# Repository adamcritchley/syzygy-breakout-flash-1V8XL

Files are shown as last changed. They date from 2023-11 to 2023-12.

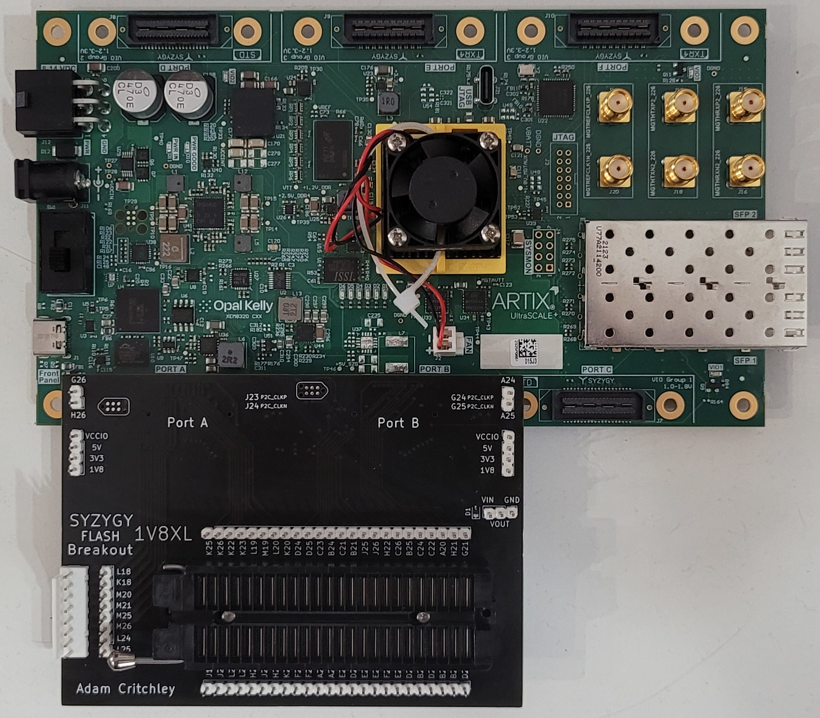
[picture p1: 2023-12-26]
images/top_on_board.jpg

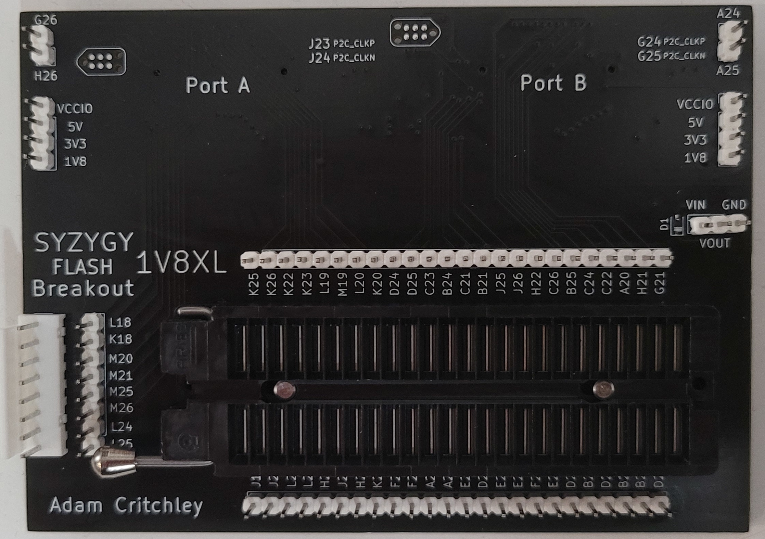
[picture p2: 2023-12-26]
images/top.jpg

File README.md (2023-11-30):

# Double-Wide SYZYGY Breakout Flash
SYZYGY 56 pin Breakout Board that uses smart VIO to support any voltage flash chip. I wanted a way to experiment with flash without having to spin a new board for each footprint or solder yet another BGA or TSOP. Flash programmers with ZIF adapters seemed like the best choice and SYZYGY would make it compatible with a wide range of FPGA boards. This is the biggest and baddest version of the other SYZYGY flash breakout boards and requires the smart VIO in the SYZYGY DNA to be set to your flash logic level. It requires two adjacent standard ports which can only be found on a handful of FPGA dev boards such as the [Opal Kelly XEM8320](https://opalkelly.com/products/xem8320/).

# Building Firmware
A prebuilt firmware has been provided in the 'firmware' directory. If you want to customize the SMART VIO then modify 'szg-flash-std.json' with the custom power values and use the official [SYZYGY tools](https://github.com/SYZYGYfpga/syzygy-tools/) repo to build the firmware. 

```bash
python ..\..\syzygy-tools\dna-tools\syzygy-tools.py -d ..\szg-dna\SZG-FLASH\szg-flash-std.json -f ..\..\syzygy-tools\pod-fw\avr-dna-fw-main.hex
```

# Fabrication
I used JLCPCB with 1oz inner and outer copper weight and the standard JLC041611-7628 impedance control.

# FPGA Development
The board has silkscreen pin designators for the Opal Kelly XEM8320. Theoretically you can use this board with any FPGA dev board that has a double-wide SYZYGY connector along with the respective controller for your flash device OR find someway to expose it to AXI and PS to use it with flashrom. As I figure out specific tools that work well then I'll update this README with tutorials.

# BOM
You can find datasheets for each component in the datasheets directory. All of the components can be bought from Mouser or Digikey. 
* Epson SG5032VAN (up to 100 MHz)
* Texas Instrument TLV1117LV
* Aries 48-6554-11
* KF2510 8-pin Vertical Connector

# Future Work
This board design is complete and tested with the Opal Kelly XEM8320. As I find/create IP and software that works with this board then I'll update this README with tutorials on how to use them. Feel free to create a GitHub issue detailing your own success story or use case.

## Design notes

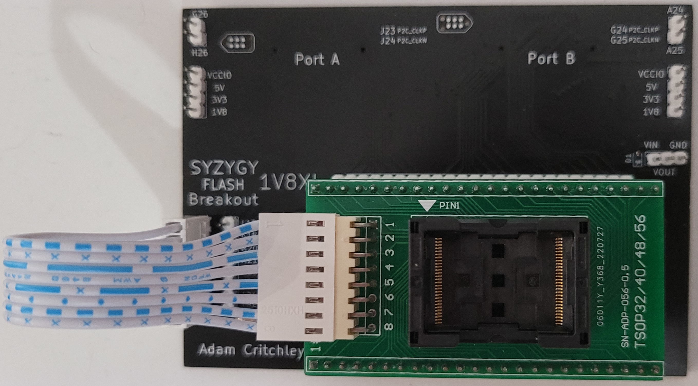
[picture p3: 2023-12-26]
images/top_with_socket.jpg

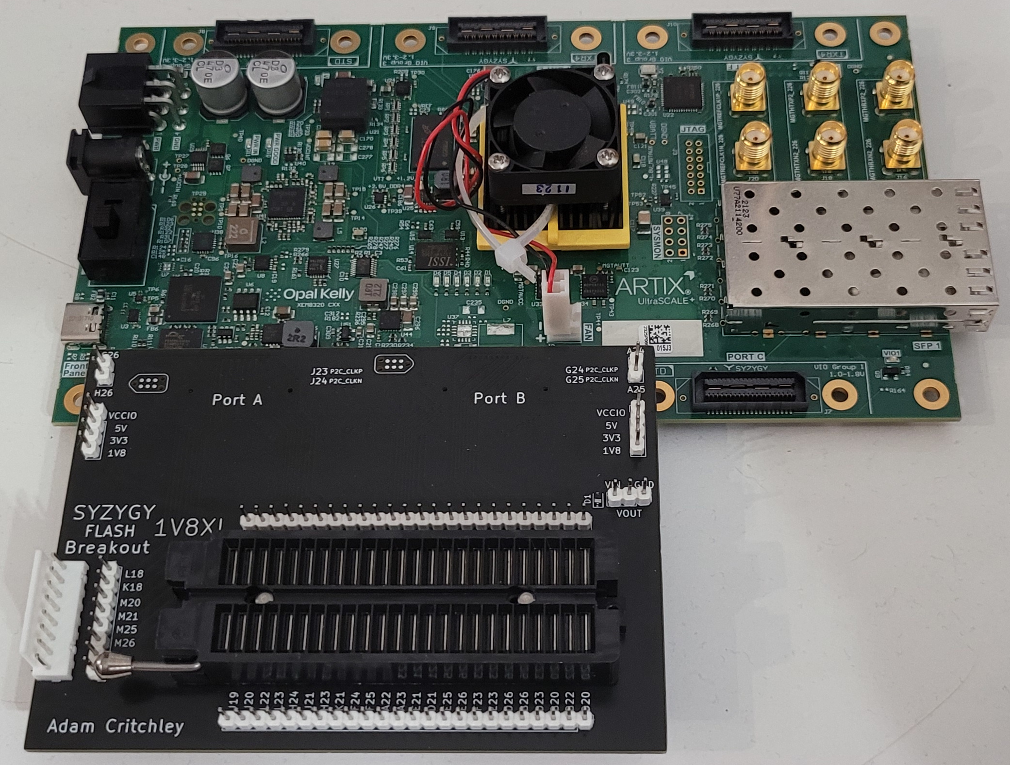
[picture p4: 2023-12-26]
images/side_on_board.jpg

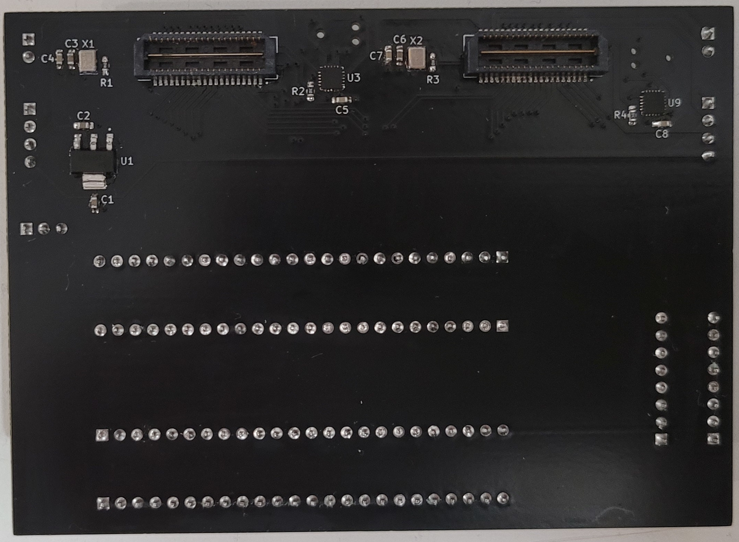
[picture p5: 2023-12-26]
images/back.jpg

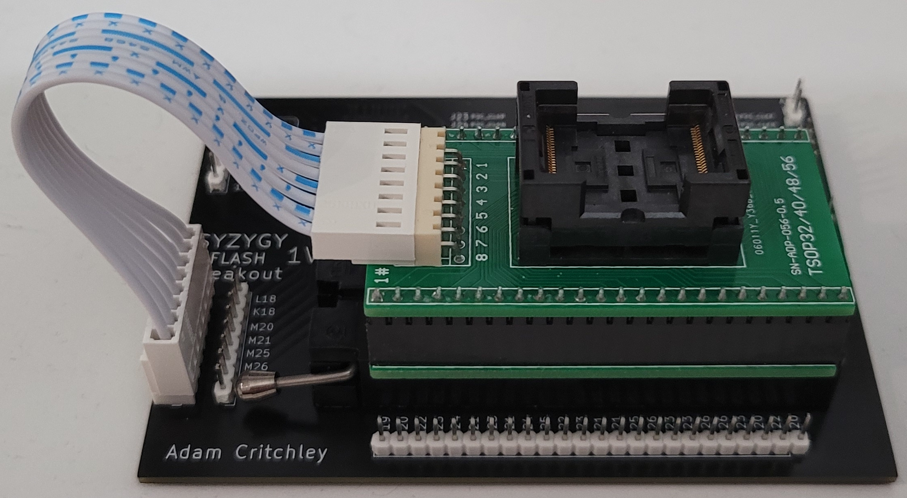
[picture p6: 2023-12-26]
images/side_with_socket.jpg

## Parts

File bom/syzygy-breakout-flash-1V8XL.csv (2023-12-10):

Index | Quantity | Part Number | Manufacturer Part Number | Description | Customer Reference | Available | Backorder | Unit Price | Extended Price USD
1 | 1 | A309-ND | 48-6554-11 | CONN IC DIP SOCKET ZIF 48POS GLD |  | 1 | 0 | 32.61000 | 32.61
2 | 1 | 114-SG3225VAN100.000000M-KEGA0CT-ND | SG3225VAN 100.000000M-KEGA0 | XTAL OSC XO 100.0000MHZ LVDS SMD |  | 1 | 0 | 3.18000 | 3.18
3 | 3 | 732-5334-ND | 61304011121 | CONN HEADER VERT 40POS 2.54MM |  | 3 | 0 | 1.53000 | 4.59
4 | 1 | WM10292-ND | 1718561008 | CONN HEADER VERT 8POS 2.54MM |  | 1 | 0 | 1.37000 | 1.37
5 | 2 | ATTINY44A-MMHRCT-ND | ATTINY44A-MMHR | IC MCU 8BIT 4KB FLASH 20VQFN |  | 2 | 0 | 1.13000 | 2.26
6 | 2 | 311-100HRCT-ND | RC0603FR-07100RL | RES 100 OHM 1% 1/10W 0603 |  | 2 | 0 | 0.10000 | 0.20
7 | 2 | 311-10.0KHRCT-ND | RC0603FR-0710KL | RES 10K OHM 1% 1/10W 0603 |  | 2 | 0 | 0.10000 | 0.20
8 | 4 | 311-1088-1-ND | CC0603KRX7R7BB104 | CAP CER 0.1UF 16V X7R 0603 |  | 4 | 0 | 0.10000 | 0.40
9 | 6 | 13-CC0603KPX7R7BB105CT-ND | CC0603KPX7R7BB105 | CAP CER 1UF 16V X7R 0603 |  | 6 | 0 | 0.14000 | 0.84
10 | 1 | BAT60AE6327HTSA1CT-ND | BAT60AE6327HTSA1 | DIODE SCHOTTKY 10V 3A SOD323-2 |  | 1 | 0 | 0.44000 | 0.44
11 | 2 | 612-QTE-020-01-F-D-A-CT-ND | QTE-020-01-F-D-A-TR | CONN HDR 40POS SMD GOLD |  | 2 | 0 | 9.62000 | 19.24
12 | 1 | 296-46351-1-ND | TLV1117LV18DCYT | IC REG LINEAR 1.8V 1A SOT223-4 |  | 1 | 0 | 1.09000 | 1.09

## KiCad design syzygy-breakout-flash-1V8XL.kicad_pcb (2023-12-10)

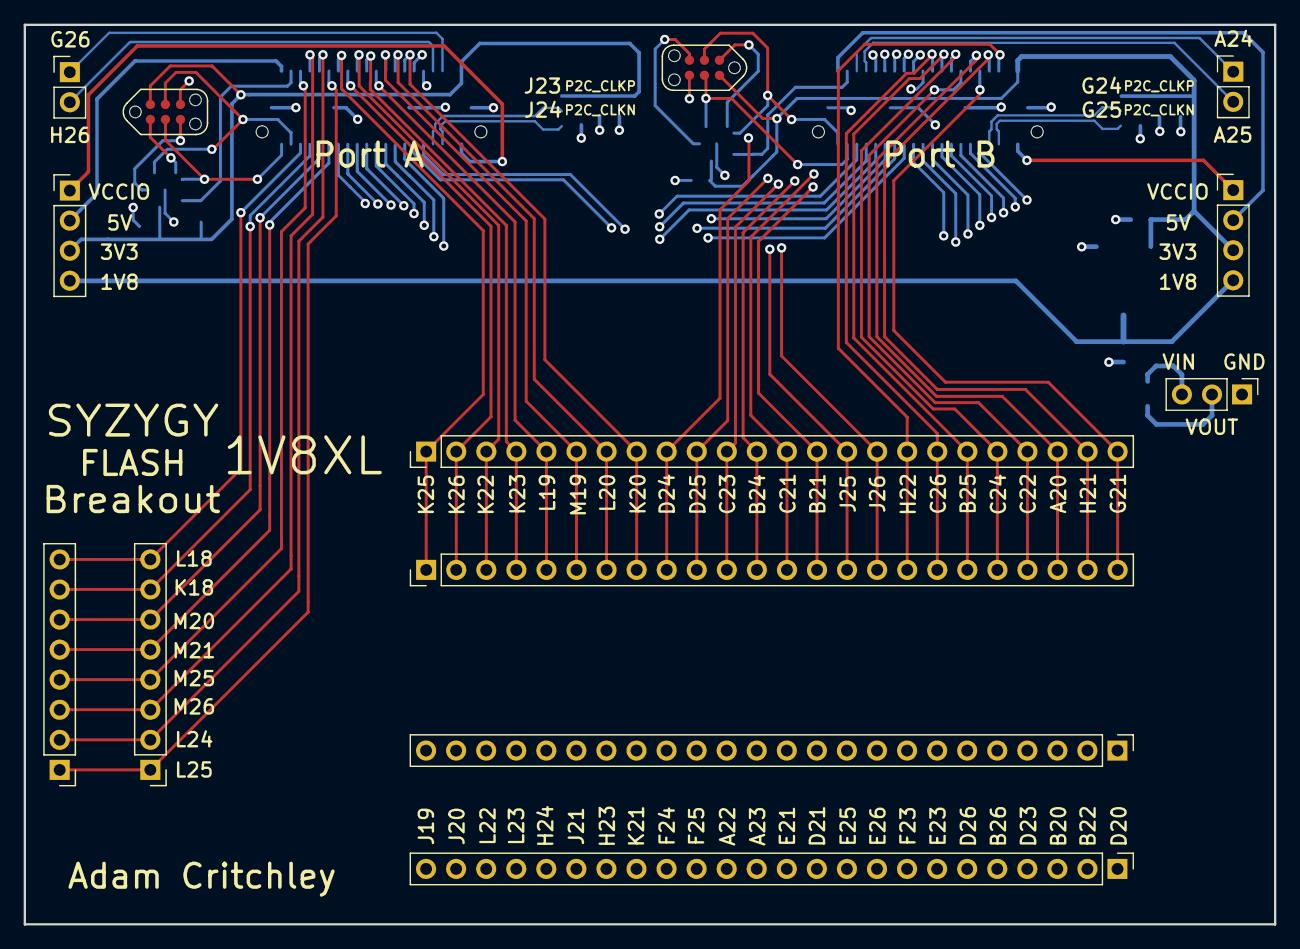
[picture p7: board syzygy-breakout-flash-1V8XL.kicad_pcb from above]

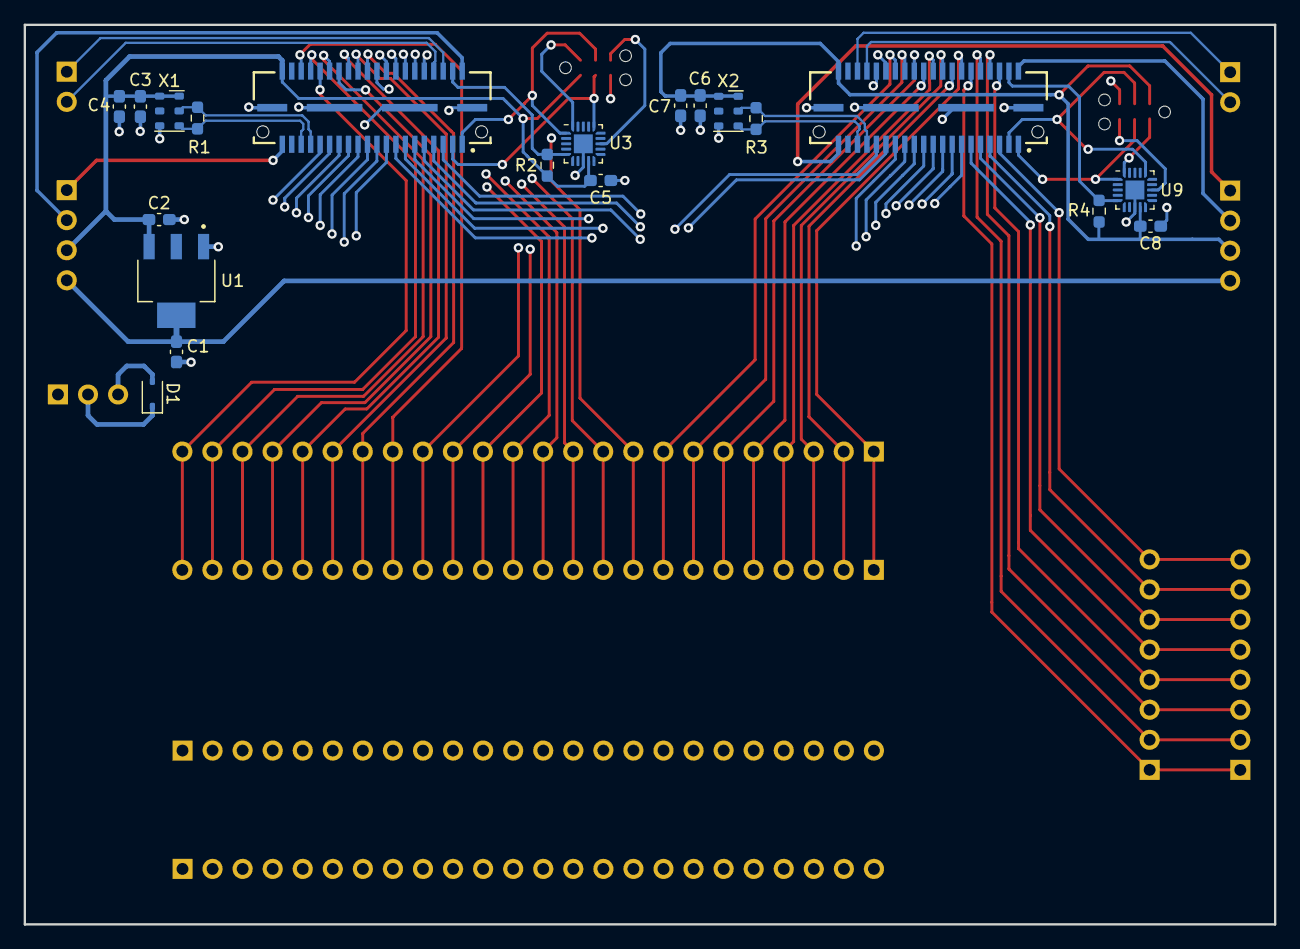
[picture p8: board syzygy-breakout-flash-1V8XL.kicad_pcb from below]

Board: 4 copper layers, 105.6 x 76.0 mm, 33 parts (20 on the bottom side), 81 nets.

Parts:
C1, C2, C3, C6: 1uF; C_0603_1608Metric_Pad1.08x0.95mm_HandSolder
C4, C5, C7, C8: 0.1uF; C_0603_1608Metric_Pad1.08x0.95mm_HandSolder
D1: BAT60AE6327HTSA1; D_SOD-323
J1, J2: QTE-020-01-F-D-A-TR; SAMTEC_QTE-020-01-F-D-A-TR
J3, J14: Conn_01x04; PinHeader_1x04_P2.54mm_Vertical
J4: Conn_01x03; PinHeader_1x03_P2.54mm_Vertical
J5, J7, J8, J9: Conn_01x24; PinHeader_1x24_P2.54mm_Vertical
J6, J10: TagConnect; TC2030-NL_SMALL
J11, J15: Conn_01x08; PinHeader_1x08_P2.54mm_Vertical
J12, J13: Conn_01x02; PinHeader_1x02_P2.54mm_Vertical
R1, R3: 100R; R_0603_1608Metric_Pad0.98x0.95mm_HandSolder
R2, R4: 10K; R_0603_1608Metric_Pad0.98x0.95mm_HandSolder
U1: TLV1117LV18DCYT; SOT230P700X180-4N
U3, U9: ATTINY44A-MMHR; QFN-20-1EP_3x3mm_P0.45mm_EP1.6x1.6mm
X1: SG3225VAN-100; Oscillator_SMD_Silicon_Labs_LGA-6_2.5x3.2mm_P1.25mm
X2: SG3225VAN-250; Oscillator_SMD_Silicon_Labs_LGA-6_2.5x3.2mm_P1.25mm

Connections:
+1V8: C1.1, J3.4, J14.4, U1.4 (VOUT)
+3V3: C2.2, C3.1, C4.1, C5.1, C6.1, C7.1, C8.1, J1.40 (+3.3V), J2.40 (+3.3V), J3.3, J6.2, J10.2, J14.3, R2.1, R4.1, U1.3 (IN), U3.9 (VCC), U9.9 (VCC), X1.1 (OE), X1.6 (Vcc), X2.1 (OE), X2.6 (Vcc)
+5V: J1.02 (+5V), J2.02 (+5V), J3.2, J14.2
/C2P_CLKN: J2.36 (C2P_CLKN), J5.17, J9.17
/C2P_CLKP: J2.34 (C2P_CLKP), J5.23, J9.23
/GPIO1: J2.06 (S1_D1P), J12.1
/GPIO2: J2.08 (S3_D1N), J12.2
/GPIO3: J1.34 (C2P_CLKP), J13.2
/GPIO4: J1.36 (C2P_CLKN), J13.1
/Peripheral MCU1/MISO: J10.1, U9.20 (PA5)
/Peripheral MCU1/~RESET: J10.5, U9.13 (~RESET/PB3)
/Peripheral MCU/MISO: J6.1, U3.20 (PA5)
/Peripheral MCU/~RESET: J6.5, U3.13 (~RESET/PB3)
/STD_P2C_CLKN: J2.35 (P2C_CLKN), R1.2, X1.4 (OUT)
/STD_P2C_CLKP: J2.33 (P2C_CLKP), R1.1, X1.5 (~OUT)
/STD_RGA: J2.04 (R_GA), R2.2, U3.5 (AREF/PA0)
/STD_SCL: J2.01 (SCL), J6.3, U3.1 (PA4)
/STD_SDA: J2.03 (SDA), J6.4, U3.16 (PA6)
/TXR_P2C_CLKN: J1.35 (P2C_CLKN), R3.2, X2.4 (OUT)
/TXR_P2C_CLKP: J1.33 (P2C_CLKP), R3.1, X2.5 (~OUT)
/TXR_RGA: J1.04 (R_GA), R4.2, U9.5 (AREF/PA0)
/TXR_SCL: J1.01 (SCL), J10.3, U9.1 (PA4)
/TXR_SDA: J1.03 (SDA), J10.4, U9.16 (PA6)
GND: C1.2, C2.1, C3.2, C4.2, C5.2, C6.2, C7.2, C8.2, J1.G1 (GND), J1.G2 (GND__1), J1.G3 (GND__2), J1.G4 (GND__3), J2.G1 (GND), J2.G2 (GND__1), J2.G3 (GND__2), J2.G4 (GND__3), J4.1, J6.6, J10.6, U1.1 (GND), U3.8 (GND), U3.21 (GND), U9.8 (GND), U9.21 (GND), X1.3 (GND), X2.3 (GND)
unnamed: D1.2 (A), J4.3
unnamed: J1.05 (S0_D0P), J11.8, J15.8
unnamed: J1.06 (S1_D1P), J11.4, J15.4
unnamed: J1.07 (S2_D0N), J11.7, J15.7
unnamed: J1.08 (S3_D1N), J11.3, J15.3
unnamed: J1.09 (S4_D2P), J11.6, J15.6
unnamed: J1.10 (S5_D3P), J11.2, J15.2
unnamed: J1.11 (S6_D2N), J11.5, J15.5
unnamed: J1.12 (S7_D3N), J11.1, J15.1
unnamed: J1.13 (S8_D4P), J7.24, J8.24
unnamed: J1.14 (S9_D5P), J5.1, J9.1
unnamed: J1.15 (S10_D4N), J7.23, J8.23
unnamed: J1.16 (S11_D5N), J5.2, J9.2
unnamed: J1.17 (S12_D6P), J7.22, J8.22
unnamed: J1.18 (S13_D7P), J5.3, J9.3
unnamed: J1.19 (S14_D6N), J7.21, J8.21
unnamed: J1.20 (S15_D7N), J5.4, J9.4
unnamed: J1.21 (S16), J7.20, J8.20
unnamed: J1.22 (S17), J5.5, J9.5
unnamed: J1.23 (S18), J7.19, J8.19
unnamed: J1.24 (S19), J5.6, J9.6
unnamed: J1.25 (S20), J7.18, J8.18
unnamed: J1.26 (S21), J5.7, J9.7
unnamed: J1.27 (S22), J7.17, J8.17
unnamed: J1.28 (S23), J5.8, J9.8
unnamed: J1.29 (S24), J7.16, J8.16
unnamed: J1.30 (S25), J5.16, J9.16
unnamed: J1.31 (S26), J7.15, J8.15
unnamed: J1.32 (S27), J5.15, J9.15
unnamed: J2.05 (S0_D0P), J7.14, J8.14
unnamed: J2.07 (S2_D0N), J7.13, J8.13
unnamed: J2.09 (S4_D2P), J7.12, J8.12
unnamed: J2.10 (S5_D3P), J5.9, J9.9
unnamed: J2.11 (S6_D2N), J7.11, J8.11
unnamed: J2.12 (S7_D3N), J5.10, J9.10
unnamed: J2.13 (S8_D4P), J7.10, J8.10
unnamed: J2.14 (S9_D5P), J5.11, J9.11
unnamed: J2.15 (S10_D4N), J7.9, J8.9
unnamed: J2.16 (S11_D5N), J5.12, J9.12
unnamed: J2.17 (S12_D6P), J7.8, J8.8
unnamed: J2.18 (S13_D7P), J5.13, J9.13
unnamed: J2.19 (S14_D6N), J7.7, J8.7
unnamed: J2.20 (S15_D7N), J5.14, J9.14
unnamed: J2.21 (S16), J7.6, J8.6
unnamed: J2.22 (S17), J5.18, J9.18
unnamed: J2.23 (S18), J7.5, J8.5
unnamed: J2.24 (S19), J5.19, J9.19
unnamed: J2.25 (S20), J7.4, J8.4
unnamed: J2.26 (S21), J5.20, J9.20
unnamed: J2.27 (S22), J7.3, J8.3
unnamed: J2.28 (S23), J5.21, J9.21
unnamed: J2.29 (S24), J7.2, J8.2
unnamed: J2.30 (S25), J5.22, J9.22
unnamed: J2.31 (S26), J7.1, J8.1
unnamed: J2.32 (S27), J5.24, J9.24
VCC: D1.1 (K), J4.2
VCCIO: J1.39 (VIO1), J2.39 (VIO1), J3.1, J14.1

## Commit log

2023-11-30 feat(pcb): push latest verified pcb design
    [syzygy-breakout-flash-1V8XL.kicad_pcb]
2023-12-10 Added BOM csv and part numbers to PCB
    [syzygy-breakout-flash-1V8XL.csv, syzygy-breakout-flash-1V8XL.kicad_pcb]
